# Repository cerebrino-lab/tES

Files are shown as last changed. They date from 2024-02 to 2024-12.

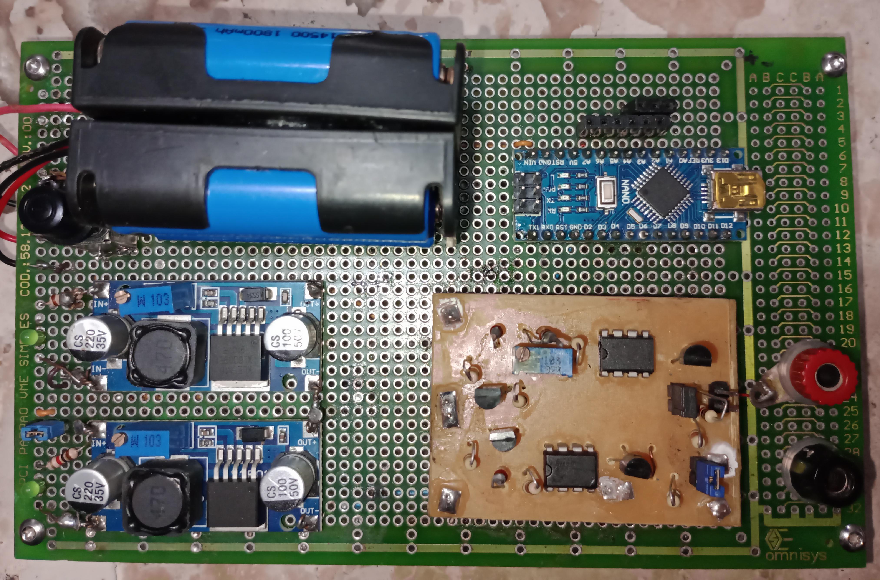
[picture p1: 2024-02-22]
tACS.jpg

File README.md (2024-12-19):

# diy_tES
Eletro-estimulador transcraniano (tES)

## ATENÇÃO!
**Esse circuito pode causar danos graves e permanentes ou até a morte.
O projeto foi publicado apenas para fiz didátidos e não deve ser usado em seres humanos ou animais em hipótese alguma.
Estejam cientes!**

## Configuração dos parâmetros através de conexão serial.

Modos de operação:
-Modo corrente contínua (ainda não implementado): estímulo por corrente contínua ajustavel de 0mA á 2mA 
-Modo senoidal: onda senoidal simples, com frequência ajustavel de 1Hz á 255Hz e corrente de 0mA á 2mA pico a pico.
-Modo cruzado: onda senoidal modulada em amplitude na fase positiva por uma segunda onda. Frequências com ajuste independente de 1Hz á 255Hz e correntes de 0mA á 2mA pico a pico.
Parâmetros das ondas:

-Frequência: ajustável de 1 a 255 Hz.

-Amplitude: ajustável de 0.1 a 2,1mA.  

tES

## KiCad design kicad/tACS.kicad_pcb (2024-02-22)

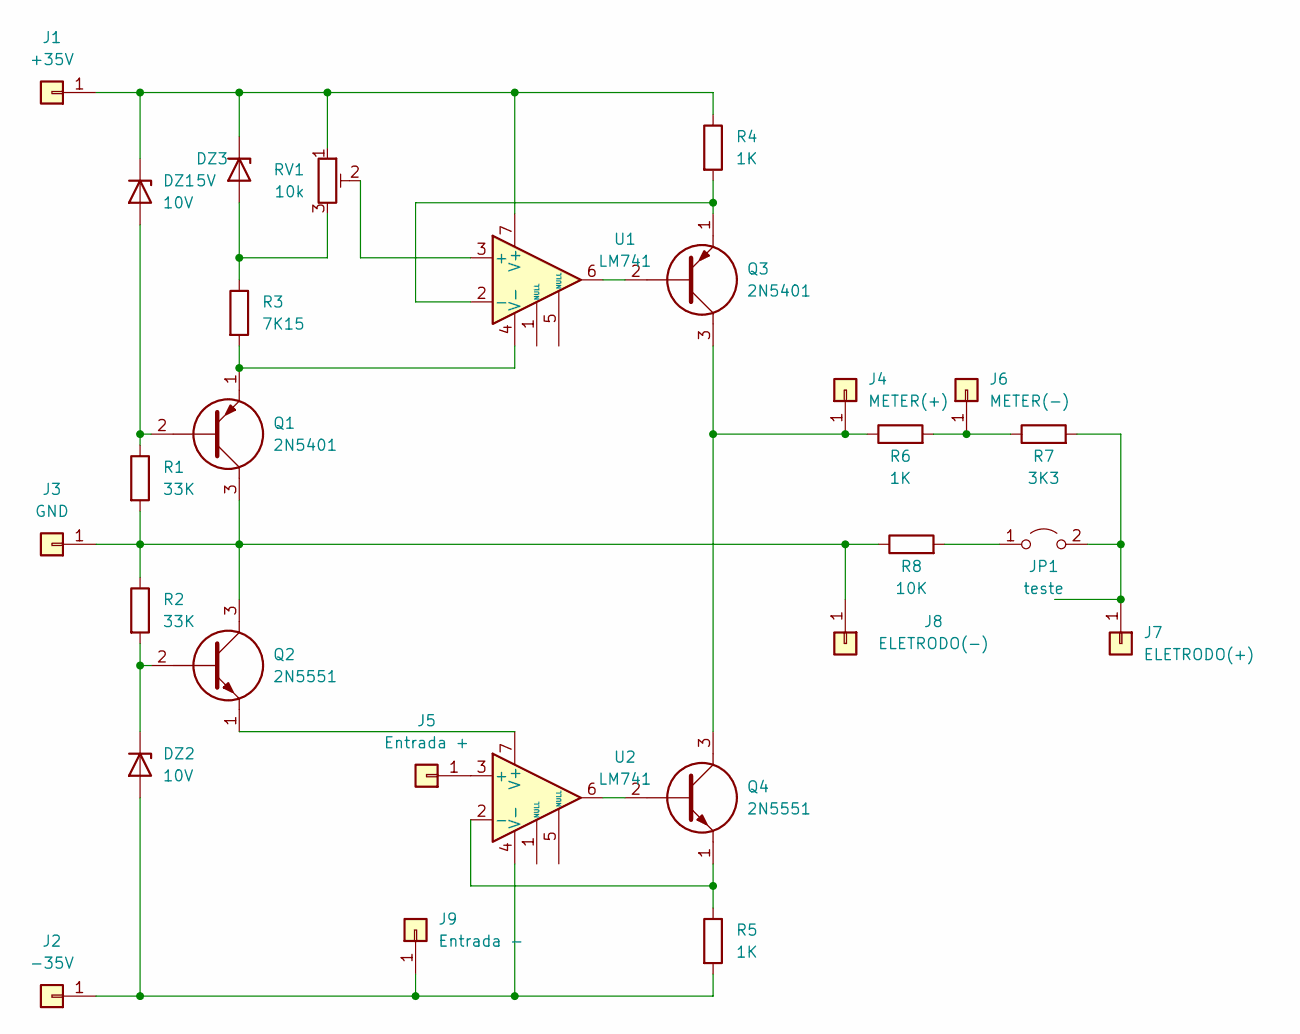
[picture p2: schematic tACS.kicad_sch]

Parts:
DZ1, DZ2: 10V; D_DO-34_SOD68_P2.54mm_Vertical_AnodeUp
DZ3: 5V; D_DO-34_SOD68_P2.54mm_Vertical_AnodeUp
J1: +35V; Pin_D0.9mm_L10.0mm_W2.4mm_FlatFork
J2: -35V; Pin_D0.9mm_L10.0mm_W2.4mm_FlatFork
J3: GND; Pin_D0.9mm_L10.0mm_W2.4mm_FlatFork
J4: METER(+); Pin_D0.9mm_L10.0mm_W2.4mm_FlatFork
J5: Entrada +; Pin_D0.9mm_L10.0mm_W2.4mm_FlatFork
J6: METER(-); Pin_D0.9mm_L10.0mm_W2.4mm_FlatFork
J7: ELETRODO(+); Pin_D0.9mm_L10.0mm_W2.4mm_FlatFork
J8: ELETRODO(-); Pin_D0.9mm_L10.0mm_W2.4mm_FlatFork
J9: Entrada -; Pin_D0.9mm_L10.0mm_W2.4mm_FlatFork
JP1: teste; PinHeader_1x02_P2.54mm_Vertical
Q1, Q3: 2N5401; TO-92L_Wide; Manufacturer_Part_Number 2N5401
Q2, Q4: 2N5551; TO-92L_Wide; Manufacturer_Part_Number 2N5551; Mouser Part Number 863-2N5551
R1, R2: 33K; R_Axial_DIN0204_L3.6mm_D1.6mm_P2.54mm_Vertical
R3: 7K15; R_Axial_DIN0204_L3.6mm_D1.6mm_P2.54mm_Vertical
R4, R5, R6: 1K; R_Axial_DIN0204_L3.6mm_D1.6mm_P2.54mm_Vertical
R7: 3K3; R_Axial_DIN0204_L3.6mm_D1.6mm_P2.54mm_Vertical
R8: 10K; R_Axial_DIN0204_L3.6mm_D1.6mm_P2.54mm_Vertical
RV1: 10k; Potentiometer_Bourns_3296W_Vertical
U1, U2: LM741; DIP-8_W7.62mm_LongPads

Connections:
unnamed: DZ1.2 (A), Q1.2, R1.1
unnamed: DZ1.1 (K), DZ3.1 (K), J1.1, R4.1, RV1.1, U1.7 (V+)
unnamed: DZ2.2 (A), J2.1, J9.1, R5.2, U2.4 (V-)
unnamed: DZ2.1 (K), Q2.2, R2.2
unnamed: DZ3.2 (A), R3.1, RV1.3
unnamed: J3.1, J8.1, Q1.3, Q2.3, R1.2, R2.1, R8.1
unnamed: J4.1, Q3.3, Q4.3, R6.1
unnamed: J5.1, U2.3 (+)
unnamed: J6.1, R6.2, R7.1
unnamed: J7.1, JP1.2 (B), R7.2
unnamed: JP1.1 (A), R8.2
unnamed: Q3.2, U1.6
unnamed: Q4.2, U2.6
unnamed: RV1.2, U1.3 (+)
unnamed: Q3.1, R4.2, U1.2 (-)
unnamed: Q1.1, R3.2, U1.4 (V-)
unnamed: Q4.1, R5.1, U2.2 (-)
unnamed: Q2.1, U2.7 (V+)

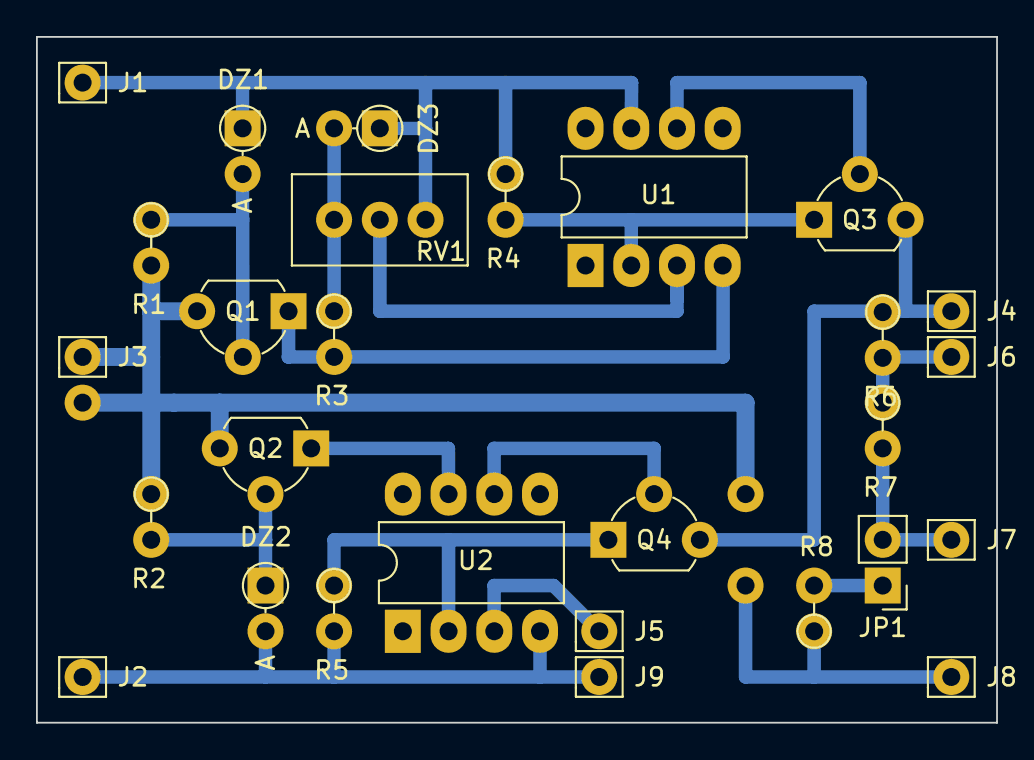
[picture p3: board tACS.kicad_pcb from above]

Board: 2 copper layers, 53.3 x 38.1 mm, 28 parts (0 on the bottom side), 18 nets.

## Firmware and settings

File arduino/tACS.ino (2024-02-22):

#include <Wire.h>
#include <Adafruit_MCP4725.h>
#include <EEPROM.h>

Adafruit_MCP4725 dac;

const PROGMEM int16_t tabela_seno[500] = {
5, 10, 15, 21, 26, 31, 36, 41, 46, 51, 56, 62, 67, 72, 77, 82, 87, 92, 97, 102, 107, 112, 117, 122, 127, 131, 
136, 141, 146, 151, 156, 160, 165, 170, 174, 179, 184, 188, 193, 197, 202, 206, 211, 215, 219, 224, 228, 232, 
237, 241, 245, 249, 253, 257, 261, 265, 269, 273, 277, 280, 284, 288, 291, 295, 299, 302, 305, 309, 312, 316, 
319, 322, 325, 328, 331, 334, 337, 340, 343, 346, 348, 351, 354, 356, 359, 361, 364, 366, 368, 371, 373, 375, 
377, 379, 381, 383, 384, 386, 388, 389, 391, 393, 394, 395, 397, 398, 399, 400, 401, 402, 403, 404, 405, 406, 
406, 407, 407, 408, 408, 409, 409, 409, 409, 409, 410, 409, 409, 409, 409, 409, 408, 408, 407, 407, 406, 406, 
405, 404, 403, 402, 401, 400, 399, 398, 397, 395, 394, 393, 391, 389, 388, 386, 384, 383, 381, 379, 377, 375, 
373, 371, 368, 366, 364, 361, 359, 356, 354, 351, 348, 346, 343, 340, 337, 334, 331, 328, 325, 322, 319, 316, 
312, 309, 305, 302, 299, 295, 291, 288, 284, 280, 277, 273, 269, 265, 261, 257, 253, 249, 245, 241, 237, 232, 
228, 224, 219, 215, 211, 206, 202, 197, 193, 188, 184, 179, 174, 170, 165, 160, 156, 151, 146, 141, 136, 131, 
127, 122, 117, 112, 107, 102, 97, 92, 87, 82, 77, 72, 67, 62, 56, 51, 46, 41, 36, 31, 26, 21, 15, 10, 5, 0, 
-5, -10, -15, -21, -26, -31, -36, -41, -46, -51, -56, -62, -67, -72, -77, -82, -87, -92, -97, -102, -107, 
-112, -117, -122, -127, -131, -136, -141, -146, -151, -156, -160, -165, -170, -174, -179, -184, -188, -193, 
-197, -202, -206, -211, -215, -219, -224, -228, -232, -237, -241, -245, -249, -253, -257, -261, -265, -269, 
-273, -277, -280, -284, -288, -291, -295, -299, -302, -305, -309, -312, -316, -319, -322, -325, -328, -331, 
-334, -337, -340, -343, -346, -348, -351, -354, -356, -359, -361, -364, -366, -368, -371, -373, -375, -377, 
-379, -381, -383, -384, -386, -388, -389, -391, -393, -394, -395, -397, -398, -399, -400, -401, -402, -403, 
-404, -405, -406, -406, -407, -407, -408, -408, -409, -409, -409, -409, -409, -410, -409, -409, -409, -409, 
-409, -408, -408, -407, -407, -406, -406, -405, -404, -403, -402, -401, -400, -399, -398, -397, -395, -394, 
-393, -391, -389, -388, -386, -384, -383, -381, -379, -377, -375, -373, -371, -368, -366, -364, -361, -359, 
-356, -354, -351, -348, -346, -343, -340, -337, -334, -331, -328, -325, -322, -319, -316, -312, -309, -305, 
-302, -299, -295, -291, -288, -284, -280, -277, -273, -269, -265, -261, -257, -253, -249, -245, -241, -237, 
-232, -228, -224, -219, -215, -211, -206, -202, -197, -193, -188, -184, -179, -174, -170, -165, -160, -156, 
-151, -146, -141, -136, -131, -127, -122, -117, -112, -107, -102, -97, -92, -87, -82, -77, -72, -67, -62, -56, 
-51, -46, -41, -36, -31, -26, -21, -15, -10, -5, 0
};

volatile bool timer_flag = false;
uint16_t index_a = 0;
uint16_t index_b = 0;
int16_t sinal_a = 0;
int16_t sinal_b = 0;
int16_t saida = 0;
uint8_t freq_a = 0;
uint8_t freq_b = 0;
uint8_t ampl_a = 0;
uint8_t ampl_b = 0;
uint8_t modo = 0;

//interrupção do timer 1
ISR(TIMER1_COMPA_vect) {
  timer_flag = true;
}

//--------------funções------------------------



char menuarray[][15] = {
	"Modo 0=N/1=C:",
	"Frequência A:",
	"Amplitude A:",
  "Frequência B:",
	"Amplitude B:",
};

void menu() {
	for (int i = 0; i <= 4; i++) {
    String valor = String(EEPROM.read(i));
		Serial.print(menuarray[i]);
    Serial.print(" = ");
    Serial.println(valor);
	}
}

void le_eeprom(){
	modo = EEPROM.read(0);
	freq_a = EEPROM.read(1);
	ampl_a = EEPROM.read(2);
	freq_b = EEPROM.read(3);
	ampl_b = EEPROM.read(4);
}


//--------------funções------------------------

void setup(void) {

  cli();  //disable interrupts
//------------------------------------------------------------------------------
// Configura o timer 1 para 200μs
TCCR1A = 0;
TCCR1B = 0;
TCNT1 = 0;

//https://www.arduinoslovakia.eu/application/timer-calculator
// 5000 Hz (16000000/((49+1)*64))
  OCR1A = 49;
// CTC
  TCCR1B |= (1 << WGM12);
// Prescaler 64
  TCCR1B |= (1 << CS11) | (1 << CS10);
// Output Compare Match A Interrupt Enable
  TIMSK1 |= (1 << OCIE1A);
//-------------------------------------------------------------------------------
  sei();  //enable interrupts

  Serial.begin(9600);
  dac.begin(0x60);
  le_eeprom();
  
}

void loop(void) {

//--------Recebe parametros pela serial
if (Serial.available() > 0){
	String entrada = Serial.readStringUntil('\n');
	//if (entrada == "c"){
		menu(); 
		Serial.println("\nAlterar valores? (s/n)");
		while(Serial.available() == 0){}
		entrada = Serial.readStringUntil('\n');
		if (entrada == "s"){
			Serial.print("\n\n<<Digite os valores>>\n\n");
			for (int i = 0; i <= 4; i++) {
				bool valida = false;
				while(valida == false){	
            Serial.print(menuarray[i]);
				    while(Serial.available() == 0){} 
            entrada = Serial.readStringUntil('\n');
            if (entrada == ""){
              String valor = String(EEPROM.read(i));
              Serial.println(valor);
              valida = true;
            }
            else{
              Serial.println(entrada);
              uint8_t valor = (uint8_t)entrada.toInt();
              if (valor >= 0 && valor <= 255){
                EEPROM.write(i, valor);
                valida = true;
              }
              else{
                Serial.println("Valor incorreto!");
              }
            }
				}		
			}
    }
	//}		
  le_eeprom();
  Serial.println("Fim");	
}

//--------incrementa os indices de acordo com as frequencias
  if (timer_flag == true) {
    timer_flag = false;
    index_a = index_a + (uint16_t)freq_a;
    index_b = index_b + (uint16_t)freq_b;
    
    if (index_a > 5000) {
      index_a = index_a - 5000;
    }
    if (index_b > 5000) {
      index_b = index_b - 5000;
    }

//--------lê os valores na tabela_seno    
    sinal_a = pgm_read_word(&(tabela_seno[index_a/10])) * (int16_t)(ampl_a / 5);
    sinal_b = pgm_read_word(&(tabela_seno[index_b/10])) * (int16_t)(ampl_b / 5);

//--------calcula os sinais de acordo com o modo
    if (modo == 0){
      saida = sinal_a;
    }
    else if(modo == 1){
      if (sinal_a < 0) {
        saida = (int16_t)((((float)sinal_b + 819) * (float)sinal_a) / 1638);
      } else {
        saida = sinal_a;
      }
    }
    else if(modo == 2){
      if (sinal_a < 0) {
        saida = (int16_t)((((float)sinal_b + 819) * (float)sinal_a) / 1638);
      } else {
        saida = 0;
      }
    }

    
    dac.setVoltage((uint16_t)saida + 2048, false);
//--------calcula ondas

  }
}
